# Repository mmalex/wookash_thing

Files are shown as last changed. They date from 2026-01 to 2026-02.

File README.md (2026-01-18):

from a livestream with wookash on Friday 2026-01-16

(youtube link forthcoming)

small Raspberry Pi RP2040 'demo' project, with 4 choc-switch buttons, rgb leds, a TFT screen, captouch around the bezel, an SWD programming header, lipo battery connection, and speaker connections.

Mostly untested - planning to order shortly to see if it works.

<p align="center">
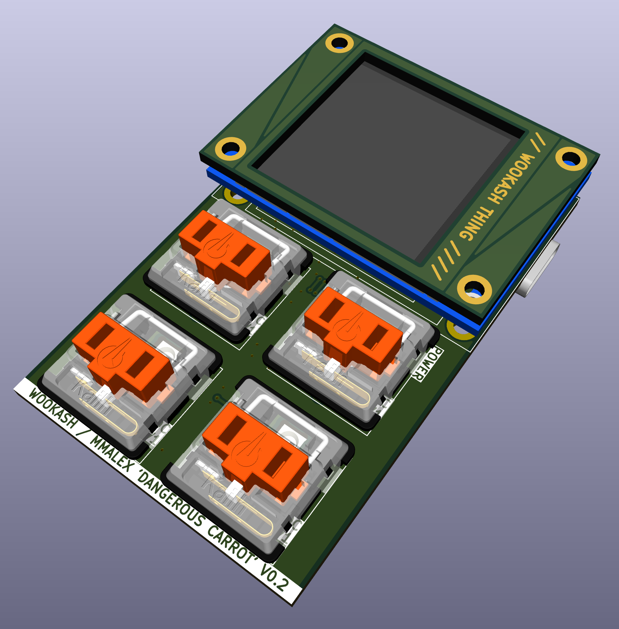
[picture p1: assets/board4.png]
3d view with fascia

</p>
<p align="center">
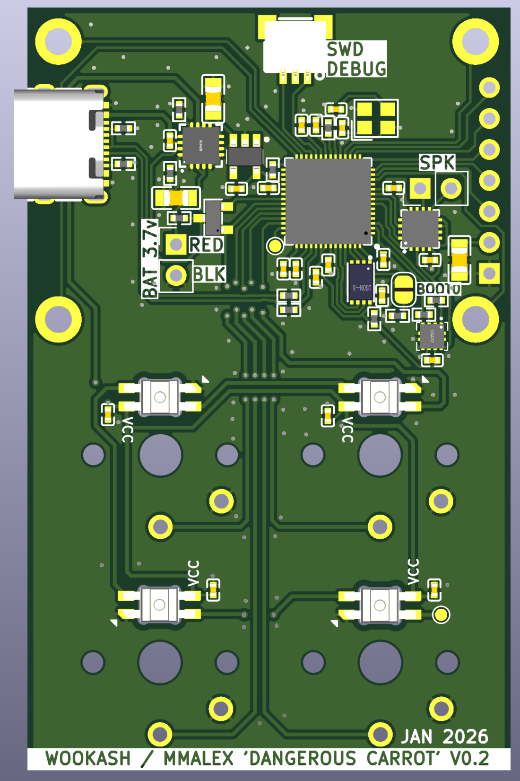
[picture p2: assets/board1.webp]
Component Side
  
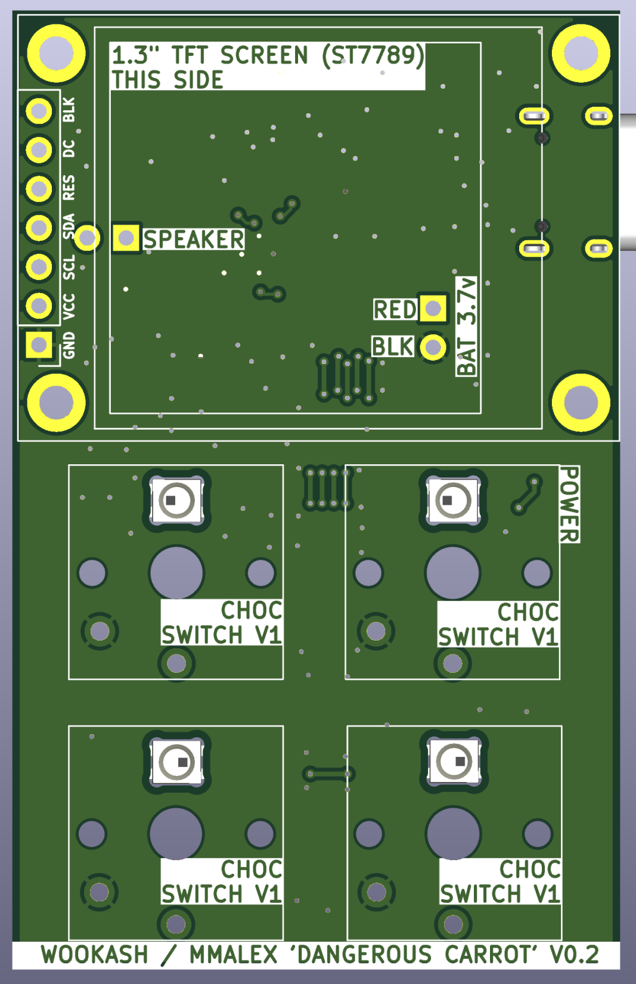
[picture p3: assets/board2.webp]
UX Side
  
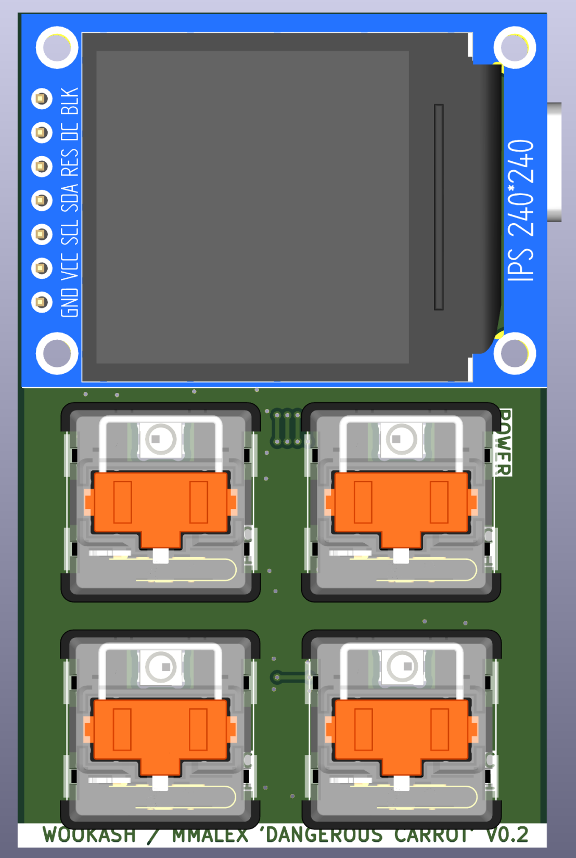
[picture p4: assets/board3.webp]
UX Side with 3d Models
  
  
</p>

See [notes.txt](notes.txt) for JLC part numbers used during the stream, and a few links.

* keyboard lib - https://github.com/ebastler/marbastlib
* easyeda2kicad - https://github.com/uPesy/easyeda2kicad.py
* jlc part search - https://yaqwsx.github.io/jlcparts/#/
* keyswitch 3d models https://github.com/koktoh/keyswitch_model.git

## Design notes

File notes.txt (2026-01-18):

33ohm - C25105
1k - C11702 (crystal)
5.1k - C25905
10k pullup - C25744

18pf crystal cap C1549
100n C307331
1u C52923
10u C15850

usbc connector - C2765186 - 5.1k cc1 & cc2
3.3v reg (big) - C6186
3.3v reg (small) - C51118 - 10u on input, 1u on output
battery charging ic - C15220 - TD to gnd; TS 10k to gnd, iset+ilm 1k to gnd, en1 +out, en2 gnd
charging led - C434448

cpu rp2040 - C2040 - 5+1 3v3 caps, 2+1 1v1 caps; run 10k hi, SS 10k hi + jumper lo
winbond flash rom - big -> C97521, tiny -> C2843335
crystal - C284155 - 1k series on xout
programming header - C160403 - 1=clk, 3=data

accelerometer - C189624; CS and SA0 high.

mosfet for beeper - C20917 - 33ohm on gate and drain to speaker.

mx keyboard - C41430893
reverse mount led - C5149201

-----
keyboard lib - https://github.com/ebastler/marbastlib
easyeda2kicad - https://github.com/uPesy/easyeda2kicad.py
jlc part search - https://yaqwsx.github.io/jlcparts/#/
keyswitch 3d models https://github.com/koktoh/keyswitch_model.git
-----
  void stdio_rtt_init(void);
  stdio_rtt_init();

"openOCDLaunchCommands": [
                "adapter speed 5000"
            ],
            "rttConfig": {
                "enabled": true,
                "address": "auto",
                "clearSearch": false,
                "polling_interval": 10,
                "rtt_start_retry": 10000,
                "decoders": [
                    {
                        "label": "Wookash Debug",
                        "port": 0,
                        "timestamp": true,
                        "type": "console"
                    }
                ]
            }

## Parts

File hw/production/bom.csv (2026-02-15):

Designator | Footprint | Quantity | Value | LCSC Part #
C1, C2, C22 | C0805 | 3 | 10u | C15850
C10, C11, C3, C4 | C0402 | 4 | 1u | C52923
C12, C13, C14, C15, C16, C17, C18, C21, C23, C5, C6, C7, C8, C9 | C0402 | 14 | 100n | C307331
C19, C20 | C0402 | 2 | 18p | C1549
CH1, CH2, CH3, CH4 | SW_choc_v1_1u | 4 | choc_v1_SW_solder
D1 | SOT-23-3_L2.9-W1.3-P1.90-LS2.4-BL-1 | 1 | BAW56 | C7502729
J1, J3 | PinHeader_1x02_P2.54mm_Vertical | 2 | 2pin
J2 | tft 1.3 | 1 | 1.3_tft
LED1, LED2 | LED_choc_6028R | 2 | choc_SK6812MINI-E | C5149201
LED3, LED4 | LED_choc_6028R-ROT | 2 | choc_SK6812MINI-E | C5149201
R1, R10, R12, R2, R7, R9 | R0402 | 6 | 5.1K | C25905
R11 | R0402 | 1 | 100K | C25803
R13, R3, R4, R8 | R0402 | 4 | 1K | C11702
R14, R15, R16, R17, R5, R6 | R0402 | 6 | 33 | C25105
TP1, TP2 | TestPoint_Pad_D1.0mm | 2 | TestPoint
U1 | QFN-16_L3.0-W3.0-P0.50-TL-EP1.7 | 1 | BQ24075RGTR | C15464
U2 | SOT-25-5_L2.9-W1.6-P0.95-LS2.8-BL | 1 | AP2112K-3.3TRG1 | C51118
U3 | LQFN-56_L7.0-W7.0-P0.4-EP | 1 | RP2040 | C2040
U4 | USON-8_L3.0-W2.0-P0.50-BL-EP | 1 | W25Q16JVUXIQ | C2843335
U5 | CONN-SMD_SM03B-SRSS-TB-LF-SN-P | 1 | SM03B-SRSS-TB(LF)(SN)(P) | C160403
U6 | LGA-12_L2.0-W2.0-P0.50-BL | 1 | LIS2DW12TR | C189624
U7 | TQFN-16_L3.0-W3.0-P0.50-BL-EP1.5 | 1 | MAX98357AETE+T | C910544
USB1 | USB-C-SMD_TYPE-C-6PIN-2MD-073 | 1 | TYPE-C 16PIN 2MD(073) | C2765186
X1 | OSC-SMD_4P-L2.5-W2.0-BL | 1 | TXM12M0004252FBCEO00T | C284155

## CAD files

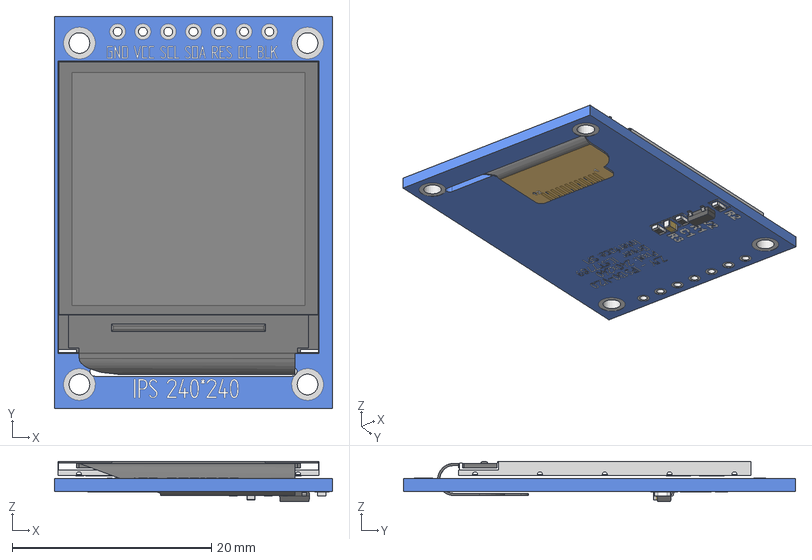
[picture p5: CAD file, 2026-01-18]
hw/3dmodels/1.3 TFT IPS - Module.stp
27.9 x 39.4 x 4.06 mm
1.3 TFT IPS - Board
1.3 TFT IPS - Flush Reverse Mount
0603 Resistor x 3
0603 Capacitor
SOT-23

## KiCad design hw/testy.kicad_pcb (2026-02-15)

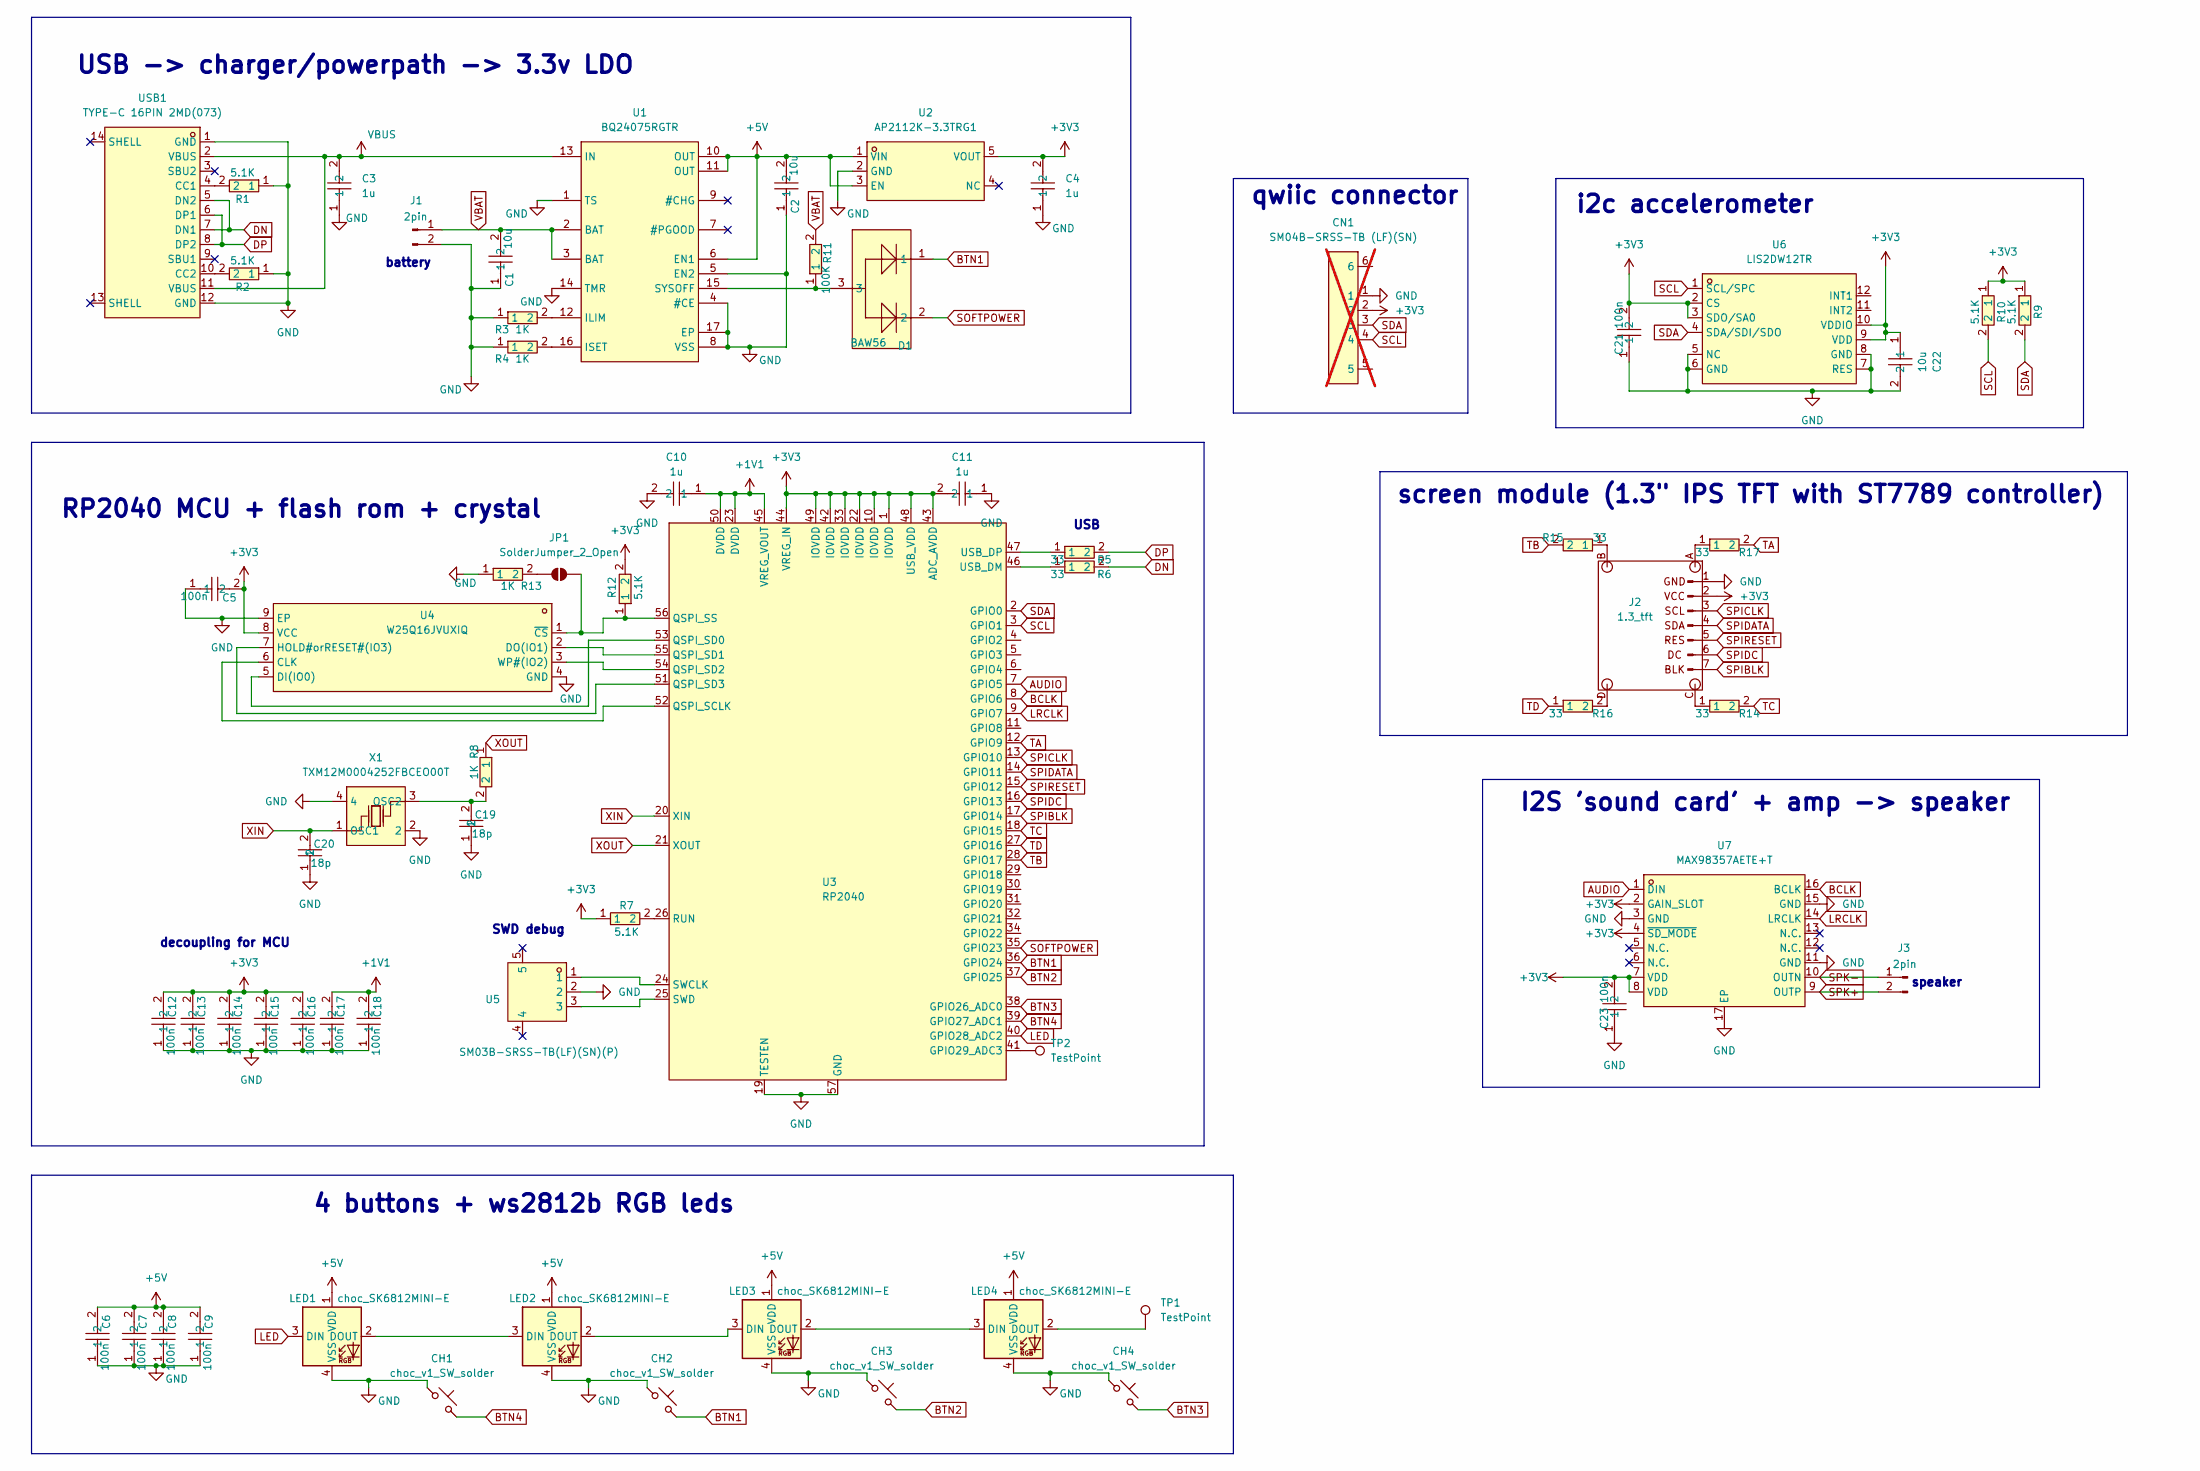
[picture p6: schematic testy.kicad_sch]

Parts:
C1, C2, C22: 10u; C0805; LCSC Part C15850
C3, C4, C10, C11: 1u; C0402; LCSC Part C52923
C5, C6, C7, C8, C9, C12, C13, C14, C15, C16, C17, C18, C21, C23: 100n; C0402; LCSC Part C307331
C19, C20: 18p; C0402; LCSC Part C1549
CH1, CH2, CH3, CH4: choc_v1_SW_solder; SW_choc_v1_1u
CN1: SM04B-SRSS-TB (LF)(SN); CONN-SMD_4P-P1.00_SM04B-SRSS-TB-LF-SN; LCSC Part C160404; not fitted
D1: BAW56; SOT-23-3_L2.9-W1.3-P1.90-LS2.4-BL-1; LCSC Part C7502729
J1, J3: 2pin; PinHeader_1x02_P2.54mm_Vertical
J2: 1.3_tft; tft 1.3
JP1: SolderJumper_2_Open; SolderJumper-2_P1.3mm_Open_RoundedPad1.0x1.5mm
LED1, LED2, LED3, LED4: choc_SK6812MINI-E; LED_choc_6028R; LCSC C5149201
R1, R2, R7, R9, R10, R12: 5.1K; R0402; LCSC Part C25905
R3, R4, R8, R13: 1K; R0402; LCSC Part C11702
R5, R6, R14, R15, R16, R17: 33; R0402; LCSC Part C25105
R11: 100K; R0402; LCSC Part C25803
TP1, TP2: TestPoint; TestPoint_Pad_D1.0mm
U1: BQ24075RGTR; QFN-16_L3.0-W3.0-P0.50-TL-EP1.7; LCSC Part C15464
U2: AP2112K-3.3TRG1; SOT-25-5_L2.9-W1.6-P0.95-LS2.8-BL; LCSC Part C51118
U3: RP2040; LQFN-56_L7.0-W7.0-P0.4-EP; LCSC Part C2040
U4: W25Q16JVUXIQ; USON-8_L3.0-W2.0-P0.50-BL-EP; LCSC Part C2843335
U5: SM03B-SRSS-TB(LF)(SN)(P); CONN-SMD_SM03B-SRSS-TB-LF-SN-P; LCSC Part C160403
U6: LIS2DW12TR; LGA-12_L2.0-W2.0-P0.50-BL; LCSC Part C189624
U7: MAX98357AETE+T; TQFN-16_L3.0-W3.0-P0.50-BL-EP1.5; LCSC Part C910544
USB1: TYPE-C 16PIN 2MD(073); USB-C-SMD_TYPE-C-6PIN-2MD-073; LCSC Part C2765186
X1: TXM12M0004252FBCEO00T; OSC-SMD_4P-L2.5-W2.0-BL; LCSC Part C284155

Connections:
+1V1: C10.1, C17.2, C18.2, U3.23 (DVDD), U3.45 (VREG_VOUT), U3.50 (DVDD)
+3V3: C4.2, C5.2, C11.2, C12.2, C13.2, C14.2, C15.2, C16.2, C21.2, C22.1, C23.2, CN1.2, J2.2, R7.1, R9.1, R10.1, R12.2, U2.5 (VOUT), U3.1 (IOVDD), U3.10 (IOVDD), U3.22 (IOVDD), U3.33 (IOVDD), U3.42 (IOVDD), U3.43 (ADC_AVDD), U3.44 (VREG_IN), U3.48 (USB_VDD), U3.49 (IOVDD), U4.8 (VCC), U6.2 (CS), U6.3 (SDO/SA0), U6.9 (VDD), U6.10 (VDDIO), U7.2 (GAIN_SLOT), U7.4 (~SD_MODE), U7.7 (VDD), U7.8 (VDD)
+5V: C2.2, C6.2, C7.2, C8.2, C9.2, LED1.1 (VDD), LED2.1 (VDD), LED3.1 (VDD), LED4.1 (VDD), U1.6 (EN1), U1.10 (OUT), U1.11 (OUT), U2.1 (VIN), U2.3 (EN)
AUDIO: U3.7 (GPIO5), U7.1 (DIN)
BCLK: U3.8 (GPIO6), U7.16 (BCLK)
BTN1: CH2.2, D1.1, U3.36 (GPIO24)
BTN2: CH3.2, U3.37 (GPIO25)
BTN3: CH4.2, U3.38 (GPIO26_ADC0)
BTN4: CH1.2, U3.39 (GPIO27_ADC1)
DN: R6.2, USB1.5 (DN2), USB1.7 (DN1)
DP: R5.2, USB1.6 (DP1), USB1.8 (DP2)
GND: C1.1, C2.1, C3.1, C4.1, C5.1, C6.1, C7.1, C8.1, C9.1, C10.2, C11.1, C12.1, C13.1, C14.1, C15.1, C16.1, C17.1, C18.1, C19.1, C20.1, C21.1, C22.2, C23.1, CH1.1, CH2.1, CH3.1, CH4.1, CN1.1, J1.2, J2.1, LED1.4 (VSS), LED2.4 (VSS), LED3.4 (VSS), LED4.4 (VSS), R1.1, R2.1, R3.1, R4.1, R13.1, U1.1 (TS), U1.4 (#CE), U1.5 (EN2), U1.8 (VSS), U1.14 (TMR), U1.17 (EP), U2.2 (GND), U3.19 (TESTEN), U3.57 (GND), U4.4 (GND), U4.9 (EP), U5.2, U6.5 (NC), U6.6 (GND), U6.7 (RES), U6.8 (GND), U7.3 (GND), U7.11 (GND), U7.15 (GND), U7.17 (EP), USB1.1 (GND), USB1.12 (GND), X1.2, X1.4
LED: LED1.3 (DIN), U3.40 (GPIO28_ADC2)
LRCLK: U3.9 (GPIO7), U7.14 (LRCLK)
unnamed: J2.A, R17.1
unnamed: J2.B, R15.1
unnamed: J2.C, R14.1
unnamed: J2.D, R16.2
unnamed: JP1.1 (A), R13.2
unnamed: JP1.2 (B), R12.1, U3.56 (QSPI_SS), U4.1 (~CS)
unnamed: LED1.2 (DOUT), LED2.3 (DIN)
unnamed: LED2.2 (DOUT), LED3.3 (DIN)
unnamed: LED3.2 (DOUT), LED4.3 (DIN)
unnamed: LED4.2 (DOUT), TP1.1
unnamed: R3.2, U1.12 (ILIM)
unnamed: R4.2, U1.16 (ISET)
unnamed: D1.3, R11.1, U1.15 (SYSOFF)
unnamed: TP2.1, U3.41 (GPIO29_ADC3)
unnamed: U3.52 (QSPI_SCLK), U4.6 (CLK)
unnamed: U3.53 (QSPI_SD0), U4.5 (DI(IO0))
unnamed: U3.55 (QSPI_SD1), U4.2 (DO(IO1))
unnamed: U3.54 (QSPI_SD2), U4.3 (WP#(IO2))
unnamed: U3.51 (QSPI_SD3), U4.7 (HOLD#orRESET#(IO3))
unnamed: R7.2, U3.26 (RUN)
unnamed: U3.24 (SWCLK), U5.1
unnamed: U3.25 (SWD), U5.3
unnamed: R6.1, U3.46 (USB_DM)
unnamed: R5.1, U3.47 (USB_DP)
unnamed: R1.2, USB1.4 (CC1)
unnamed: R2.2, USB1.10 (CC2)
unnamed: C19.2, R8.2, X1.3 (OSC2)
SCL: CN1.4, R10.2, U3.3 (GPIO1), U6.1 (SCL/SPC)
SDA: CN1.3, R9.2, U3.2 (GPIO0), U6.4 (SDA/SDI/SDO)
SOFTPOWER: D1.2, U3.35 (GPIO23)
SPIBLK: J2.7, U3.17 (GPIO14)
SPICLK: J2.3, U3.13 (GPIO10)
SPIDATA: J2.4, U3.14 (GPIO11)
SPIDC: J2.6, U3.16 (GPIO13)
SPIRESET: J2.5, U3.15 (GPIO12)
SPK+: J3.2, U7.9 (OUTP)
SPK-: J3.1, U7.10 (OUTN)
TA: R17.2, U3.12 (GPIO9)
TB: R15.2, U3.28 (GPIO17)
TC: R14.2, U3.18 (GPIO15)
TD: R16.1, U3.27 (GPIO16)
VBAT: C1.2, J1.1, R11.2, U1.2 (BAT), U1.3 (BAT)
VBUS: C3.2, U1.13 (IN), USB1.2 (VBUS), USB1.11 (VBUS)
XIN: C20.2, U3.20 (XIN), X1.1 (OSC1)
XOUT: R8.1, U3.21 (XOUT)

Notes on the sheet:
4 buttons + ws2812b RGB leds
i2c accelerometer
SWD debug
speaker
qwiic connector
RP2040 MCU + flash rom + crystal
USB -> charger/powerpath -> 3.3v LDO
USB
screen module (1.3" IPS TFT with ST7789 controller)
I2S 'sound card' + amp -> speaker
battery
decoupling for MCU

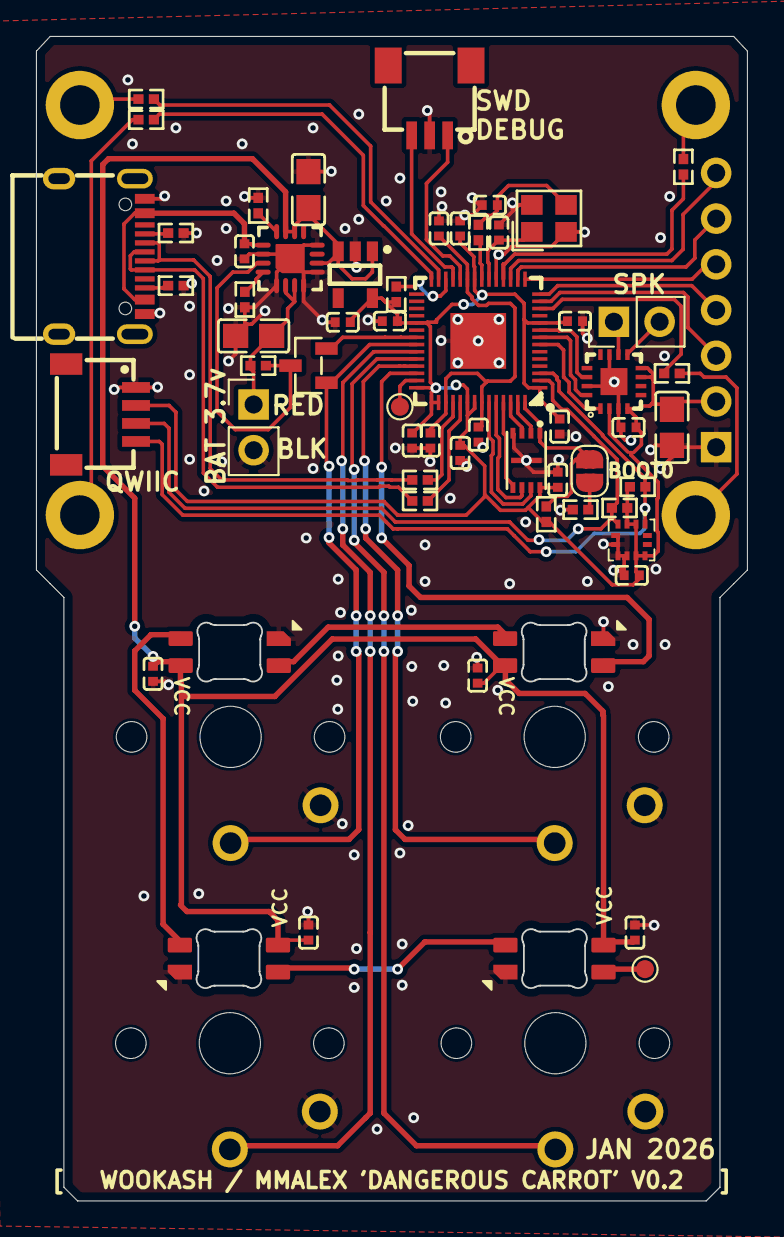
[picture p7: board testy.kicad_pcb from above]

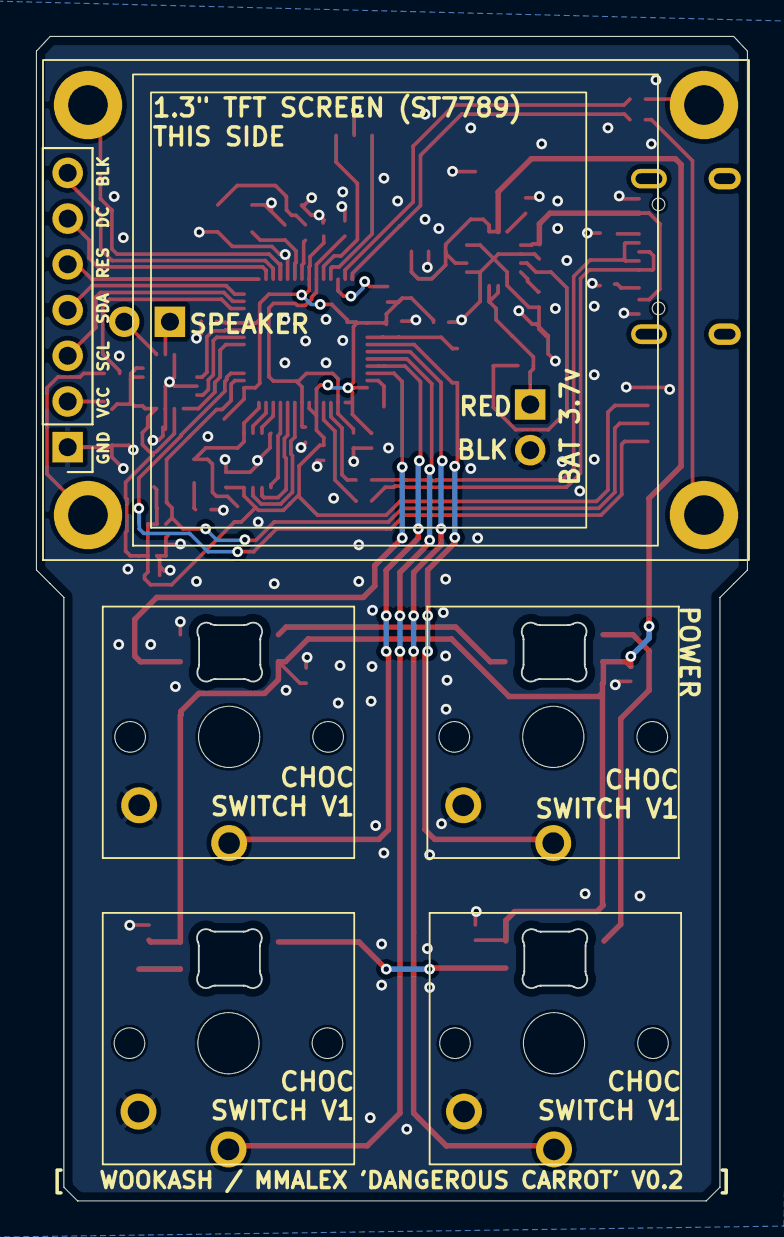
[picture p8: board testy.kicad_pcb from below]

Board: 2 copper layers, 39.5 x 64.7 mm, 65 parts (5 on the bottom side), 59 nets.

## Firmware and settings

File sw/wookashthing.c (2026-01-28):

#include <assert.h>
#include <stdio.h>
#include <stdlib.h>
#include <stdio.h>
#include <string.h>
#include <math.h>

#include "hardware/clocks.h"
#include "hardware/dma.h"
#include "hardware/irq.h"
#include "hardware/spi.h"
#include "hardware/i2c.h"
#include "audio_i2s.pio.h"
#include "ws2812.pio.h"

// screen SPI / gpio
#define SCREEN_PIN_SCL 10
#define SCREEN_PIN_SDA 11
#define SCREEN_PIN_RES 12
#define SCREEN_PIN_DC 13
#define SCREEN_PIN_BLK 14
#define SCREEN_SPI spi1

// audio i2s
#define AUDIO_PIN_DATA 5
#define AUDIO_PIN_BCLK 6
#define AUDIO_PIN_LRCLK 7
#define AUDIO_PIO pio0
#define AUDIO_PIO_FUNCTION GPIO_FUNC_PIO0

// ws2812
#define LEDS_PIN 28
#define LEDS_PIO pio1
#define LEDS_PIO_FUNCTION GPIO_FUNC_PIO1

// i2c for accelerometer
#define ACCEL_PIN_SDA 0
#define ACCEL_PIN_SCL 1
#define ACCEL_I2C i2c0
#define ACCEL_ADDR 0x19 // 0011001b

#define SOFTPOWER_PIN 23
#define BUTTON_PINS 24
    // buttons are:
    // 3 0 aka 8 1
    // 2 1     4 2
    // leds are:
    // 0 1
    // 3 2
    #define BTN_BIT_TL 8
    #define BTN_BIT_TR 1
    #define BTN_BIT_BL 4
    #define BTN_BIT_BR 2
    #define LED_IDX_TL 0
    #define LED_IDX_TR 1
    #define LED_IDX_BL 3
    #define LED_IDX_BR 2

int buttons_get(void) { return ((gpio_get_all() >> BUTTON_PINS) & 15) ^ 15; }

void buttons_init(void) {
  for (int i = 0; i < 4; ++i) {
    gpio_init(BUTTON_PINS + i);
    gpio_set_dir(BUTTON_PINS + i, GPIO_IN);
    gpio_pull_up(BUTTON_PINS + i);
  }
}

// CTRL1 - 20h - ODR[4], MODE[2], LP_MODE[2] -> 0101=100hz, 0110=200hz
// mode 01 is high perf; so we want 0b01010100
// CTRL2 - 21h - BOOT RESET 0 CS_PU_DISC BDU IF_ADD_INC I2C_DISABLE SIM
// we want 0b00000100
#define ACCEL_WHOAMI_ADDR 0x0f
#define ACCEL_CTRL1_ADDR 0x20
#define ACCEL_CTRL2_ADDR 0x21
#define ACCEL_DATA_ADDR 0x28
#define ACCEL_WHOAMI 0x44
#define ACCEL_CTRL1 0b01010100
#define ACCEL_CTRL2 0b00000100

static bool have_accel = false;
static int16_t accel_data_raw[3] = {0};

static int audio_dma_chan = -1;
#define AUDIO_BUFFER_SIZE_SH 9
#define AUDIO_BUFFER_SIZE (1 << AUDIO_BUFFER_SIZE_SH)
static int16_t audio_buf[2][AUDIO_BUFFER_SIZE] __attribute__((aligned(AUDIO_BUFFER_SIZE*2)));
static volatile int audio_buf_idx = 0;

#define BOUNCE_VOL 16000
static int vol = 0;

static void __isr audio_dma_irq0_handler(void) {
  dma_hw->ints0 = 1u << audio_dma_chan;
  audio_buf_idx ^= 1;
  dma_channel_set_read_addr(audio_dma_chan, audio_buf[audio_buf_idx], false);
  dma_channel_set_trans_count(audio_dma_chan, AUDIO_BUFFER_SIZE, true);
  int16_t *dst = audio_buf[audio_buf_idx^1];

  for (int i = 0; i < AUDIO_BUFFER_SIZE; ++i) {
    if (vol>0) { vol=(vol*255)/256; if (vol<2) vol=0; }
    dst[i] = (((rand()&0x7fff)-16384) * vol) >> 15;
  }
}

static int accel_i2c_write(const void *mem, int count) {
  return i2c_write_blocking_until(ACCEL_I2C, ACCEL_ADDR, (const uint8_t *)mem, count, false, make_timeout_time_us(100000));
}
static int accel_i2c_read(void *mem, int count) {
  return i2c_read_blocking_until(ACCEL_I2C, ACCEL_ADDR, (uint8_t *)mem, count, false, make_timeout_time_us(100000));
}
static int accel_i2c_write_reg(int reg, int val) {
  uint8_t data[2] = {reg, val};
  return accel_i2c_write(data, 2);
}
static int accel_i2c_read_regs(int reg, int count, uint8_t *buf) {
  uint8_t data[1] = {reg};
  accel_i2c_write(data, 1);
  return accel_i2c_read(buf, count);
}
static int accel_i2c_read_reg(int reg) {
  uint8_t data[2] = {reg, 0};
  accel_i2c_read_regs(reg, 1, data + 1);
  return data[1];
}

// ST7789 command set
#define CMD_SWRESET 0x01
#define CMD_SLPOUT 0x11
#define CMD_COLMOD 0x3A
#define CMD_MADCTL 0x36
#define CMD_CASET 0x2A
#define CMD_RASET 0x2B
#define CMD_RAMWR 0x2C
#define CMD_INVON 0x21
#define CMD_INVOFF 0x20
#define CMD_NORON 0x13
#define CMD_DISPON 0x29

static void spi_write_byte(uint8_t b) { spi_write_blocking(SCREEN_SPI, &b, 1); }

static void lcd_write_cmd(uint8_t cmd) {
  gpio_put(SCREEN_PIN_DC, 0);
  spi_write_byte(cmd);
}

static void lcd_write_data(uint8_t data) {
  gpio_put(SCREEN_PIN_DC, 1);
  spi_write_byte(data);
}

static void lcd_write_data16(uint16_t data) {
  lcd_write_data((uint8_t)(data >> 8));
  lcd_write_data((uint8_t)(data & 0xFF));
}

static void init_palette(void);

static int spi_dma_chan;
static dma_channel_config spi_dma_cfg;

static uint8_t screen[120][120];
static uint16_t palette[256];

static void lcd_reset(void) {
  gpio_put(SCREEN_PIN_RES, 0);
  sleep_ms(10);
  gpio_put(SCREEN_PIN_RES, 1);
  sleep_ms(150);
}

static void lcd_set_window(uint16_t x0, uint16_t y0, uint16_t x1, uint16_t y1) {
  lcd_write_cmd(CMD_CASET);
  lcd_write_data16(x0);
  lcd_write_data16(x1);

  lcd_write_cmd(CMD_RASET);
  lcd_write_data16(y0);
  lcd_write_data16(y1);

  lcd_write_cmd(CMD_RAMWR);
}

static void screen_init(void) {
  spi_init(SCREEN_SPI, 100 * 1000 * 1000);
  spi_set_format(SCREEN_SPI, 8, SPI_CPOL_1, SPI_CPHA_1, SPI_MSB_FIRST);
  gpio_set_function(SCREEN_PIN_SCL, GPIO_FUNC_SPI);
  gpio_set_function(SCREEN_PIN_SDA, GPIO_FUNC_SPI);

  gpio_init(SCREEN_PIN_RES);
  gpio_init(SCREEN_PIN_DC);
  gpio_init(SCREEN_PIN_BLK);

  gpio_set_dir(SCREEN_PIN_RES, GPIO_OUT);
  gpio_set_dir(SCREEN_PIN_DC, GPIO_OUT);
  gpio_set_dir(SCREEN_PIN_BLK, GPIO_OUT);

  gpio_put(SCREEN_PIN_DC, 0);
  gpio_put(SCREEN_PIN_BLK, 0); // backlight off until display is on

  spi_dma_chan = dma_claim_unused_channel(true);

  spi_dma_cfg = dma_channel_get_default_config(spi_dma_chan);
  channel_config_set_transfer_data_size(&spi_dma_cfg, DMA_SIZE_8);
  channel_config_set_dreq(&spi_dma_cfg, spi_get_dreq(SCREEN_SPI, true));
  channel_config_set_read_increment(&spi_dma_cfg, true);
  channel_config_set_write_increment(&spi_dma_cfg, false);
  dma_channel_configure(spi_dma_chan, &spi_dma_cfg, &spi_get_hw(SCREEN_SPI)->dr, NULL, 0, false);

  sleep_ms(40);
  lcd_reset();

  lcd_write_cmd(CMD_SWRESET);
  sleep_ms(150);

  lcd_write_cmd(CMD_SLPOUT);
  sleep_ms(10);

  lcd_write_cmd(CMD_COLMOD);
  lcd_write_data(0x55); // 16-bit color
  sleep_ms(10);

  lcd_write_cmd(CMD_MADCTL);
  lcd_write_data(0x08); // matches Adafruit generic init
  sleep_ms(10);

  lcd_write_cmd(CMD_INVON);
  sleep_ms(10);

  lcd_write_cmd(CMD_NORON);
  sleep_ms(10);

  lcd_write_cmd(CMD_DISPON);
  sleep_ms(10);

  gpio_put(SCREEN_PIN_BLK, 1); // backlight on

  init_palette();
}

static void init_palette(void) {
  for (uint16_t i = 0; i < 256; i++) {
    uint16_t r5 = i >> 3;
    uint16_t g6 = 0;
    uint16_t b5 = 0;
    uint16_t color = (uint16_t)((b5 << 11) | (g6 << 5) | r5);
    if (i == 255) color = 0xffff;
    palette[i] = (color >> 8) + (color << 8);
  }
}

static void lcd_fill_scanline(uint32_t *dst, uint16_t y_src) {
  for (uint16_t x = 0; x < 120; x++) {
    uint16_t color = palette[screen[y_src][x]];
    *dst++ = (uint32_t)color | ((uint32_t)color << 16);
  }
}

static void screen_flip(void) {
  const uint16_t width = 240;
  const uint16_t height = 240;
  static uint32_t scanline[2][120];
  uint32_t *front = scanline[0];
  uint32_t *back = scanline[1];
  const uint32_t line_bytes = width * 2;

  lcd_set_window(0, 0, width - 1, height - 1);
  gpio_put(SCREEN_PIN_DC, 1);

  lcd_fill_scanline(front, 0);
  dma_channel_set_read_addr(spi_dma_chan, front, false);
  dma_channel_set_trans_count(spi_dma_chan, line_bytes, true);

  for (uint16_t y_src = 0; y_src < height / 2; y_src++) {
    if (y_src + 1 < height / 2) {
      lcd_fill_scanline(back, (uint16_t)(y_src + 1));
    }

    dma_channel_wait_for_finish_blocking(spi_dma_chan);
    dma_channel_set_read_addr(spi_dma_chan, front, false);
    dma_channel_set_trans_count(spi_dma_chan, line_bytes, true);
    dma_channel_wait_for_finish_blocking(spi_dma_chan);

    if (y_src + 1 < height / 2) {
      uint32_t *tmp = front;
      front = back;
      back = tmp;
      dma_channel_set_read_addr(spi_dma_chan, front, false);
      dma_channel_set_trans_count(spi_dma_chan, line_bytes, true);
    }
  }
}

void leds_init(void) {
  pio_sm_claim(LEDS_PIO, 0);
  gpio_set_function(LEDS_PIN, LEDS_PIO_FUNCTION);
  uint offset = pio_add_program(LEDS_PIO, &ws2812_program);
  ws2812_program_init(LEDS_PIO, 0, offset, LEDS_PIN, 800000, false);
}

#define RGB(r,g,b)  (((g)<<24)|((r)<<16)|((b)<<8))

static void leds_set(uint32_t grb0[4]) {
  pio_sm_put_blocking(LEDS_PIO, 0, grb0[0]);
  pio_sm_put_blocking(LEDS_PIO, 0, grb0[1]);
  pio_sm_put_blocking(LEDS_PIO, 0, grb0[2]);
  pio_sm_put_blocking(LEDS_PIO, 0, grb0[3]);
}

void accel_init(void) {
  i2c_init(ACCEL_I2C, 400 * 1000);
  gpio_set_function(ACCEL_PIN_SDA, GPIO_FUNC_I2C);
  gpio_set_function(ACCEL_PIN_SCL, GPIO_FUNC_I2C);

  accel_i2c_write_reg(ACCEL_CTRL1_ADDR, ACCEL_CTRL1);
  accel_i2c_write_reg(ACCEL_CTRL2_ADDR, ACCEL_CTRL2);
  int id = accel_i2c_read_reg(ACCEL_WHOAMI_ADDR);
  have_accel = id == ACCEL_WHOAMI;
  printf("Accelerometer ID: %02x expected: %02x\n", id, ACCEL_WHOAMI);
}

void accel_read(void) {
  if (have_accel) {
    accel_i2c_read_regs(ACCEL_DATA_ADDR, 6, (uint8_t *)accel_data_raw);
    printf("Acceleration: %5d %5d %5d\n", accel_data_raw[0], accel_data_raw[1], accel_data_raw[2]);
  } else {
    accel_data_raw[0] = 0;
    accel_data_raw[1] = 0;
    accel_data_raw[2] = 0;
  }
}

void audio_init(void) {
  // audio
  gpio_set_function(AUDIO_PIN_DATA, AUDIO_PIO_FUNCTION);
  gpio_set_function(AUDIO_PIN_BCLK, AUDIO_PIO_FUNCTION);
  gpio_set_function(AUDIO_PIN_LRCLK, AUDIO_PIO_FUNCTION);

  pio_sm_claim(AUDIO_PIO, 0);
  uint offset = pio_add_program(AUDIO_PIO, &audio_i2s_program);
  audio_i2s_program_init(AUDIO_PIO, 0, offset, AUDIO_PIN_DATA, AUDIO_PIN_BCLK);
  static_assert(AUDIO_PIN_BCLK < AUDIO_PIN_LRCLK, "BCLK must be less than LRCLK, otherwise use the swapped program");

  uint32_t system_clock_frequency = clock_get_hz(clk_sys);
  uint32_t sample_freq = 16000;
  uint32_t divider = system_clock_frequency * 4 / sample_freq; // avoid arithmetic overflow
  pio_sm_set_clkdiv_int_frac(AUDIO_PIO, 0, divider >> 8u, divider & 0xffu);

  pio_sm_set_enabled(AUDIO_PIO, 0, true);

  audio_dma_chan = dma_claim_unused_channel(true);
  dma_channel_config audio_dma_cfg = dma_channel_get_default_config(audio_dma_chan);
  channel_config_set_transfer_data_size(&audio_dma_cfg, DMA_SIZE_16);
  channel_config_set_read_increment(&audio_dma_cfg, true);
  channel_config_set_write_increment(&audio_dma_cfg, false);
  channel_config_set_dreq(&audio_dma_cfg, pio_get_dreq(AUDIO_PIO, 0, true));
  dma_channel_set_irq0_enabled(audio_dma_chan, true);
  irq_set_exclusive_handler(DMA_IRQ_0, audio_dma_irq0_handler);
  irq_set_enabled(DMA_IRQ_0, true);
  dma_channel_configure(
      audio_dma_chan,
      &audio_dma_cfg,
      &AUDIO_PIO->txf[0],
      audio_buf[0],
      AUDIO_BUFFER_SIZE,
      true);


}

static inline int maxi(int a, int b) { return a > b ? a : b; }

int main(void) {
  gpio_init(SOFTPOWER_PIN);
  gpio_set_dir(SOFTPOWER_PIN, GPIO_OUT);
  gpio_put(SOFTPOWER_PIN, 0); // 1=off, 0=on
  
  void stdio_rtt_init(void);
  stdio_rtt_init();

  screen_init();
  audio_init();
  leds_init();
  accel_init();
  buttons_init();
  sleep_ms(100);
  uint32_t leds[4] = {}; // grb order
  leds_set(leds);

  static int ballx = 60 * 256;
  static int bally = 60 * 256;
  static int vx = 0;
  static int vy = 0;

  uint32_t last_time_button_press = time_us_32();
  uint32_t tr_btn_not_down_time = time_us_32();
  while (true) {

    int btns = buttons_get();
    uint32_t now = time_us_32();
    if (btns) last_time_button_press = now;
    if (!(btns & BTN_BIT_TR)) tr_btn_not_down_time = now;
    if ((now - last_time_button_press) > 10*1000000 || (now - tr_btn_not_down_time) > 2*1000000) {
        // power down
        gpio_put(SOFTPOWER_PIN, 1);
        sleep_ms(100);
        // if we're still here, it means we must be on usb power...
    }
    memset(leds, 0, sizeof(leds));
    if (btns & BTN_BIT_TL) leds[LED_IDX_TL] = RGB(255,0,0);
    if (btns & BTN_BIT_TR) leds[LED_IDX_TR] = RGB(0,255,0);
    if (btns & BTN_BIT_BL) leds[LED_IDX_BL] = RGB(0,0,255);
    if (btns & BTN_BIT_BR) leds[LED_IDX_BR] = RGB(200,128,0);
    
    leds_set(leds);

    int ax = accel_data_raw[0];
    int ay = accel_data_raw[1];
    vx = (vx * 255) / 256;
    vy = (vy * 255) / 256;
    vx += (ay / 64);
    vy -= (ax / 64);
    ballx += vx;
    bally += vy;
    int bounce = 200;
    #define VOLUME 10
    if (ballx < 15 * 256) {
      ballx = 15 * 256;
      vol = maxi(vol, abs(vx) * VOLUME);
      vx = (abs(vx) * bounce) >> 8;
    }
    if (ballx > (120 - 15) * 256) {
      ballx = (120 - 15) * 256;
      vol = maxi(vol, abs(vx) * VOLUME);
      vx = -(abs(vx) * bounce) >> 8;
    }
    if (bally < 15 * 256) {
      bally = 15 * 256;
      vol = maxi(vol, abs(vy) * VOLUME);
      vy = (abs(vy) * bounce) >> 8;
    }
    if (bally > (120 - 15) * 256) {
      bally = (120 - 15) * 256;
      vol = maxi(vol, abs(vy) * VOLUME);
      vy = -(abs(vy) * bounce) >> 8;
    }
    for (int y = 0; y < 120; y++) {
      int yy = (y * 256 - bally);
      yy *= yy;
      for (int x = 0; x < 120; x++) {
        int xx = (x * 256 - ballx);
        xx *= xx;
        int dd = (xx + yy);
        int c = screen[y][x];
        if (c > 4)
          c -= 4;
        else
          c = 0;
        if (dd < 15 * 15 * 65536) c = 255;
        screen[y][x] = c;
      }
    }
    screen_flip();
    accel_read();
  }
}

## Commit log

2026-01-18 first commit - added some silkscreen, pinswapped the buttons, added a fascia
    [testy.kicad_pcb, testy.kicad_sch, testy_fascia.kicad_pcb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]
2026-01-18 add 3d model of screen
    [1.3 TFT IPS - Module.stp]
2026-01-18 move 3d models
    [1.3 TFT IPS - Module.stp]
2026-01-18 hw files as they were ordered at jlc
    [bom.csv, designators.csv, positions.csv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]
2026-02-15 change 1M pullup to 100k
    [testy.kicad_pcb, testy.kicad_sch]
2026-02-15 add updated prod files
    [bom.csv]
